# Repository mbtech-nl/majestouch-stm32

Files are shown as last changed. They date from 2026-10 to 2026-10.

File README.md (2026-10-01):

# majestouch-stm32

A drop-in replacement controller for the full-size Filco Majestouch, built
around an STM32F072. It replaces the stock daughterboard, plugs into the same
36-pin header on the main PCB and runs [QMK](https://qmk.fm); the QMK keyboard
definition is included.

> [!WARNING]
> **Untested.** The first boards are on order and have not been built or
> verified on a keyboard yet. Order and build at your own risk until this
> notice is gone.

<p align="center">
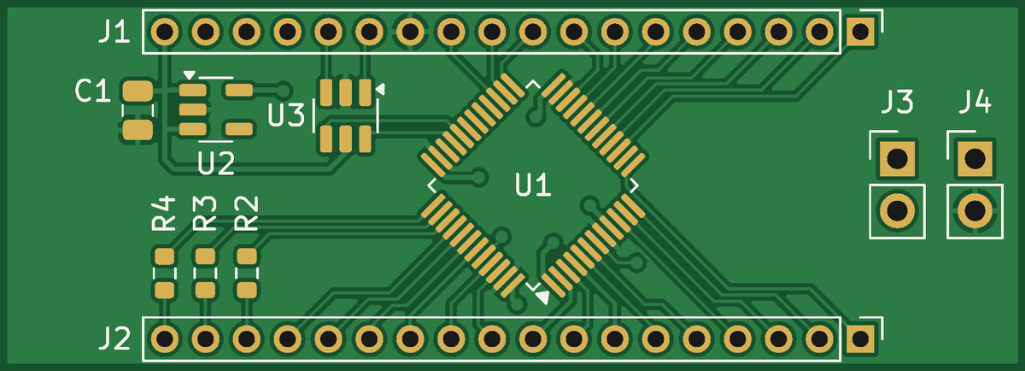
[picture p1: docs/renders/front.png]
Component side: STM32F072 at 45 degrees between the two header rows, USB ESD chip, LDO and LED resistors
  
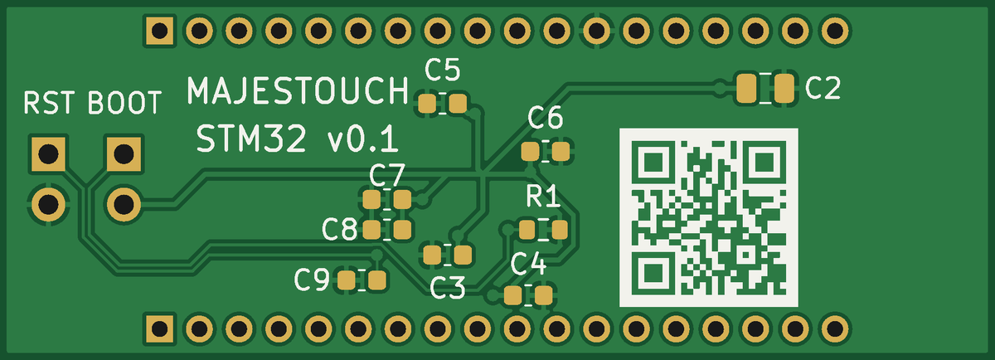
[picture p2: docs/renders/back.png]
Outward side: decoupling capacitors, BOOT and RST jumper holes, name, version and a QR code to this repository
  
</p>
<p align="center"><sub>Component side (faces the main PCB) and outward side, rendered from the KiCad board.</sub></p>

## Background

I was looking for a replacement for my 2010 Majestouch, but gave it a full
service and fresh keycaps instead. Reading up on it, I came across the
[Kitten Paw](https://deskthority.net/wiki/Costar_replacement_controllers)
(ATmega32U2 + 74HC154), the replacement controller for Costar boards such as
the Filco, about a decade after everyone else did, and
[Majestouch-2-TKL-Replacement-Controller](https://github.com/calliah333/Majestouch-2-TKL-Replacement-Controller),
which does the same for the Majestouch 2 TKL with an STM32.

PS/2 left my desk a long time ago, and over USB the stock controller only does
6KRO. I wanted my NKRO back, so I tried making one myself. It's my first open
source hardware project, and the design turned out to be quite
straightforward. It takes the STM32 approach to the full-size board and keeps
it simple:

- **STM32F072CBT6**: crystal-less USB (HSI48 + clock recovery), internal
  flash, ROM bootloader with USB DFU, and 5 V-tolerant pins for the lock LEDs.
  All 26 matrix lines are scanned directly, with no decoder chip.
- **NKRO over USB** (on by default in the QMK definition), where the stock
  controller only did 6KRO over USB.
- **16 components**, LQFP-48 and 0603/0805 passives: hand-solderable.
- USB ESD protection (USBLC6-2SC6) and a 3.3 V LDO (AP2112K-3.3).
- 50 × 18 mm, 2 layers, standard process at any PCB fab.

## Compatibility

Built for and measured on a full-size ANSI Majestouch with main PCB
`CST 104/5/6 Main PCBA Rev 1.2` and stock daughterboard
`CST-DAUGHTER PCBA Rev 3.1 ESD`.

The full-size Filcos below share the same 36-pin header and matrix according
to deskthority, and the Kitten Paw is listed for the same main PCBs, so they
are expected to work, but are untested with this board:

| Keyboard | Main PCB |
|---|---|
| Majestouch (FKBN104/105) | CST-FKB/N-104/5/6 Main PCBA Rev 1.0 / 1.2 (2010) |
| Majestouch Linear R | CST-F104/5/6/8 Main PCB Rev 2.1 (2010) |
| Majestouch 2 | CST-F104/5/6/8 Main PCB Rev 3.0 (2012) |

Full NKRO needs a diode per key. Filco marks those boards with an N in the
model code (FKB**N**…, "N-key rollover using separate diodes"); the cheaper
2KRO models without it work too, but ghost on some key combinations.

Compare your stock controller with the pinout below before fitting. The QMK
definition currently has the ANSI layout only; ISO boards work electrically
but need an ISO layout for the two extra keys. The Majestouch TKL uses a
different header and does not fit.

## Repository

```
kicad/                       KiCad 7 project (schematic, board, design rules)
firmware/majestouch_stm32/   QMK keyboard definition
tools/check.py               validation: schematic, firmware pins and board
tools/fab.py                 fabrication package (Gerbers, drill, BOM)
docs/                        board renders, photos of the stock controller
```

`tools/check.py` checks the schematic against the STM32 datasheet pinout and
the Filco header map, checks that every pin in the QMK definition lands on the
right net, and runs KiCad's design rule check on the board. It needs KiCad 7
(`kicad-cli` and the `pcbnew` Python module).

## Header pinout

From the Filco Majestouch table on deskthority's
[controller matrix traces](https://deskthority.net/wiki/Controller_matrix_traces)
page, cross-checked pin for pin against the
[Kitten Paw schematic](https://deskthority.net/wiki/File:Kitten_Paw_20160418_Schematic.svg).
The component side
faces the main PCB; seen from that side, pin 1 is top-right, pins 1–18 run
right to left, and pin 19 sits directly below pin 1.

| Pin | Signal | STM32 | | Pin | Signal | STM32 |
|---|---|---|---|---|---|---|
| 1 | COL0 | PA5 | | 19 | ROW_K | PA3 |
| 2 | ROW_A | PA6 | | 20 | COL1 | PA2 |
| 3 | ROW_B | PA7 | | 21 | ROW_L | PA1 |
| 4 | ROW_C | PB0 | | 22 | COL2 | PA0 |
| 5 | ROW_D | PB1 | | 23 | COL3 | PF1 |
| 6 | ROW_E | PB2 | | 24 | ROW_M | PF0 |
| 7 | ROW_F | PB10 | | 25 | ROW_N | PC15 |
| 8 | ROW_G | PB11 | | 26 | ROW_O | PC14 |
| 9 | ROW_H | PB12 | | 27 | ROW_P | PC13 |
| 10 | ROW_I | PB13 | | 28 | ROW_Q | PB9 |
| 11 | ROW_J | PB14 | | 29 | COL4 | PB8 |
| 12 | GND | | | 30 | ROW_R | PB7 |
| 13 | USB D+ | ESD → PA12 | | 31 | COL5 | PB6 |
| 14 | USB D− | ESD → PA11 | | 32 | COL6 | PB5 |
| 15 | n/c | | | 33 | COL7 | PB4 |
| 16 | n/c | | | 34 | LED Num Lock | PB3 |
| 17 | n/c | | | 35 | LED Caps Lock | PA15 |
| 18 | VBUS | LDO in | | 36 | LED Scroll Lock | PA14 |

Pins 15 and 16 are tied to GND on the main PCB; this board leaves 15–17
unconnected.

<p align="center">
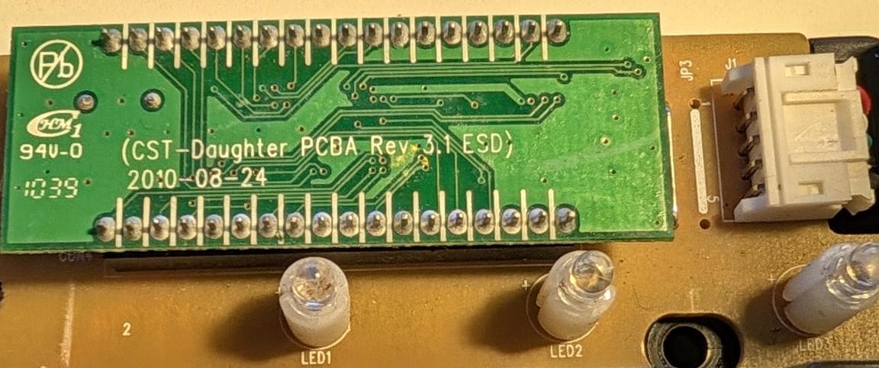
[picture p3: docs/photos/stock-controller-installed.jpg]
Stock Filco controller installed in the keyboard, solder side up, next to the lock LEDs and the USB cable connector
  
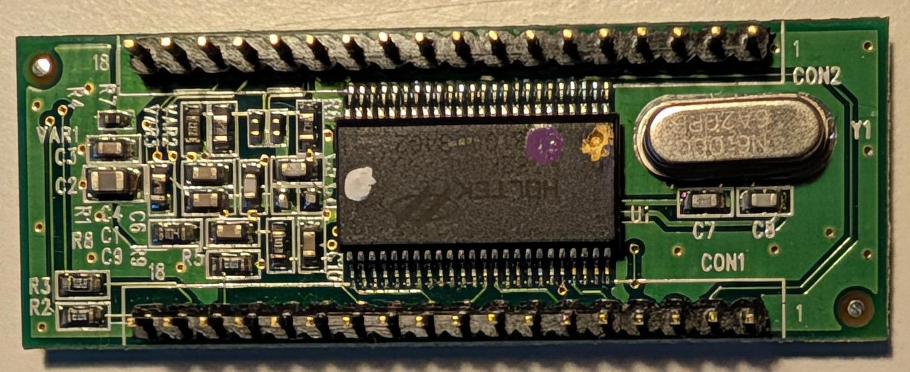
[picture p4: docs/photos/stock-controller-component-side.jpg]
Stock Filco controller removed, component side: Holtek MCU, crystal and the two header rows CON2 (pins 1-18) and CON1 (pins 19-36)
  
</p>
<p align="center"><sub>The stock controller this board replaces: installed, solder side up, next to the lock LEDs and the USB cable connector; and removed, component side, oriented like the render above (CON2 = pins 1–18 on top, pin 1 at the right).</sub></p>

## Circuit

- **USB**: D+/D− pass through the USBLC6-2SC6 flow-through (in on pins 1/3,
  out on 6/4), so no route bypasses the clamp. The STM32's internal pull-up
  handles D+.
- **Power**: VBUS → AP2112K-3.3. Each MCU supply pin has its own decoupling
  cap: 1 µF + 10 nF on VDDA, 100 nF on VDD, VDDIO2 and VBAT.
- **Matrix**: 18 rows driven, 8 columns read (QMK `COL2ROW`). The main PCB
  has no pull-ups to 5 V on the matrix lines, so the 3.6 V-only pins
  (PA0–PA7, PB0/PB1) are safe.
- **Lock LEDs**: the LED anodes sit on +5 V on the main PCB. The MCU sinks
  each LED through a 10 k resistor from a 5 V-tolerant pin in open-drain mode,
  like the stock controller (~0.3 mA).
- **BOOT / RESET**: 2.54 mm jumper holes. BOOT0 has a 10 k pull-down, NRST
  100 nF to GND.

**Board:** 50 × 18 mm, 2 layers, 1.2 mm FR-4. 0.15 mm tracks and clearance
(0.25 mm for power), 0.3 mm vias, GND pour on both sides. The MCU sits at 45°
so each side fans out to one header row. ICs, C1 and the LED resistors are on
the component side (facing the main PCB), the other passives on the outward
side. The outward side carries the reference designators, BOOT/RST labels and
a QR code linking to this repository.

## Making one

> [!CAUTION]
> Seriously: don't build one yet. Wait until the first boards have been
> assembled and tested, and this banner is gone.

### Board

```sh
cd tools
python3 check.py   # validate first
python3 fab.py
```

This builds `kicad/fab/majestouch_stm32-gerbers-<rev>.zip` (Gerbers and drill
files, accepted by any PCB fab) plus `bom.csv` with the parts used and what an
equivalent needs. Tagged releases have both attached, built and validated by GitHub
Actions (`.github/workflows/release.yml`).

Order settings: 2 layers, FR-4, 1.2 mm (the stock board's thickness; 1.6 mm
fits too), HASL lead-free or ENIG. The design stays within standard rules
(0.15 mm track/space, 0.3 mm drills). If your fab prints an order number on
the board (JLCPCB does by default), choose the option without it, so it
doesn't land on the QR code. `cpl.csv` (pick-and-place) is only needed if the
fab assembles the board.

### Parts

| Ref | Part | Package |
|---|---|---|
| U1 | STM32F072CBT6 | LQFP-48 |
| U2 | AP2112K-3.3 | SOT-23-5 |
| U3 | USBLC6-2SC6 | SOT-23-6 |
| C1 | 4.7 µF | 0805 |
| C2 | 10 µF | 0805 |
| C3–C6, C9 | 100 nF | 0603 |
| C7 | 1 µF | 0603 |
| C8 | 10 nF | 0603 |
| R1–R4 | 10 k | 0603 |
| J1, J2 | 2.0 mm pin header, 1 × 40 strip snapped to 2 × 18 | |
| J3, J4 | 2.54 mm 1 × 2 header (optional) | |

Any equivalent part works: X5R/X7R capacitors at 10 V or more, 1 % or 5 %
resistors.

### Assembly

U1, U2, U3, C1 and R2–R4 go on the component side, the other passives on the
back; every part is labelled on the silkscreen. Mind the pin-1 triangles on
U1, U2 and U3: U2 and U3 short VBUS to GND when rotated. Solder the pin
headers last, with the plastic on the component side, then fit the board in
place of the stock controller.

### Firmware

Copy `firmware/majestouch_stm32` into `qmk_firmware/keyboards/`, then:

```sh
qmk compile -kb majestouch_stm32 -km default
```

First flash: bridge the BOOT jumper while plugging in USB (or bridge BOOT and
tap RESET) to start the STM32's DFU bootloader, then
`qmk flash -kb majestouch_stm32 -km default`. After that, hold Esc while
plugging in to get back to the bootloader.

The default keymap is a standard full-size ANSI layout. The Caps/Num/Scroll
LEDs follow the host's lock state.

## Verified on the keyboard

Measured on the target keyboard before ordering:

- outline and header position match the stock board (1:1 print);
- no connection from VBUS to any matrix pin on the main PCB;
- lock LED anodes on +5 V, active low;
- enough height between the boards; stock board 1.2 mm thick.

## References

- [Controller matrix traces](https://deskthority.net/wiki/Controller_matrix_traces)
  (deskthority wiki): the Filco Majestouch header pinout and matrix.
- [Kitten Paw schematic](https://deskthority.net/wiki/File:Kitten_Paw_20160418_Schematic.svg)
  by Bpiphany (public domain): the reference replacement controller for the
  full-size Filco, used to cross-check the header.
- [Costar replacement controllers](https://deskthority.net/wiki/Costar_replacement_controllers)
  (deskthority wiki): the Kitten Paw and its relatives.
- [Majestouch-2-TKL-Replacement-Controller](https://github.com/calliah333/Majestouch-2-TKL-Replacement-Controller):
  an STM32 replacement controller for the Majestouch 2 TKL.
- [STM32F072CB datasheet](https://www.st.com/resource/en/datasheet/stm32f072cb.pdf) (DS9826),
  [USBLC6-2 datasheet](https://www.st.com/resource/en/datasheet/usblc6-2.pdf),
  [AP2112 datasheet](https://www.diodes.com/assets/Datasheets/AP2112.pdf).

## License

MIT, see [LICENSE](LICENSE). This covers the hardware, the tools and the QMK
keyboard definition. Firmware built with QMK includes QMK itself, which is
GPL-2.0-or-later, so compiled binaries fall under the GPL.

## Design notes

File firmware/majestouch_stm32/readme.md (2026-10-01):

# majestouch_stm32

QMK keyboard definition for the [majestouch-stm32](https://github.com/mbtech-nl/majestouch-stm32)
replacement controller (STM32F072) for the full-size Filco Majestouch.

* Keyboard maintainer: [mbtech-nl](https://github.com/mbtech-nl)
* Hardware supported: majestouch-stm32 controller board in a full-size Filco Majestouch
* Hardware availability: https://github.com/mbtech-nl/majestouch-stm32

Copy this folder into `qmk_firmware/keyboards/`, then:

    qmk compile -kb majestouch_stm32 -km default
    qmk flash -kb majestouch_stm32 -km default

## Bootloader

* **First flash**: bridge the BOOT jumper while plugging in USB (or bridge BOOT and tap RESET).
* **Bootmagic reset**: hold Esc while plugging in.

## License

The files in this folder are MIT licensed, like the rest of the project.
Firmware built from them includes QMK, which is GPL-2.0-or-later, so compiled
binaries are covered by the GPL.

`tools/check.py` verifies the matrix and LED pins in these files against the
schematic.

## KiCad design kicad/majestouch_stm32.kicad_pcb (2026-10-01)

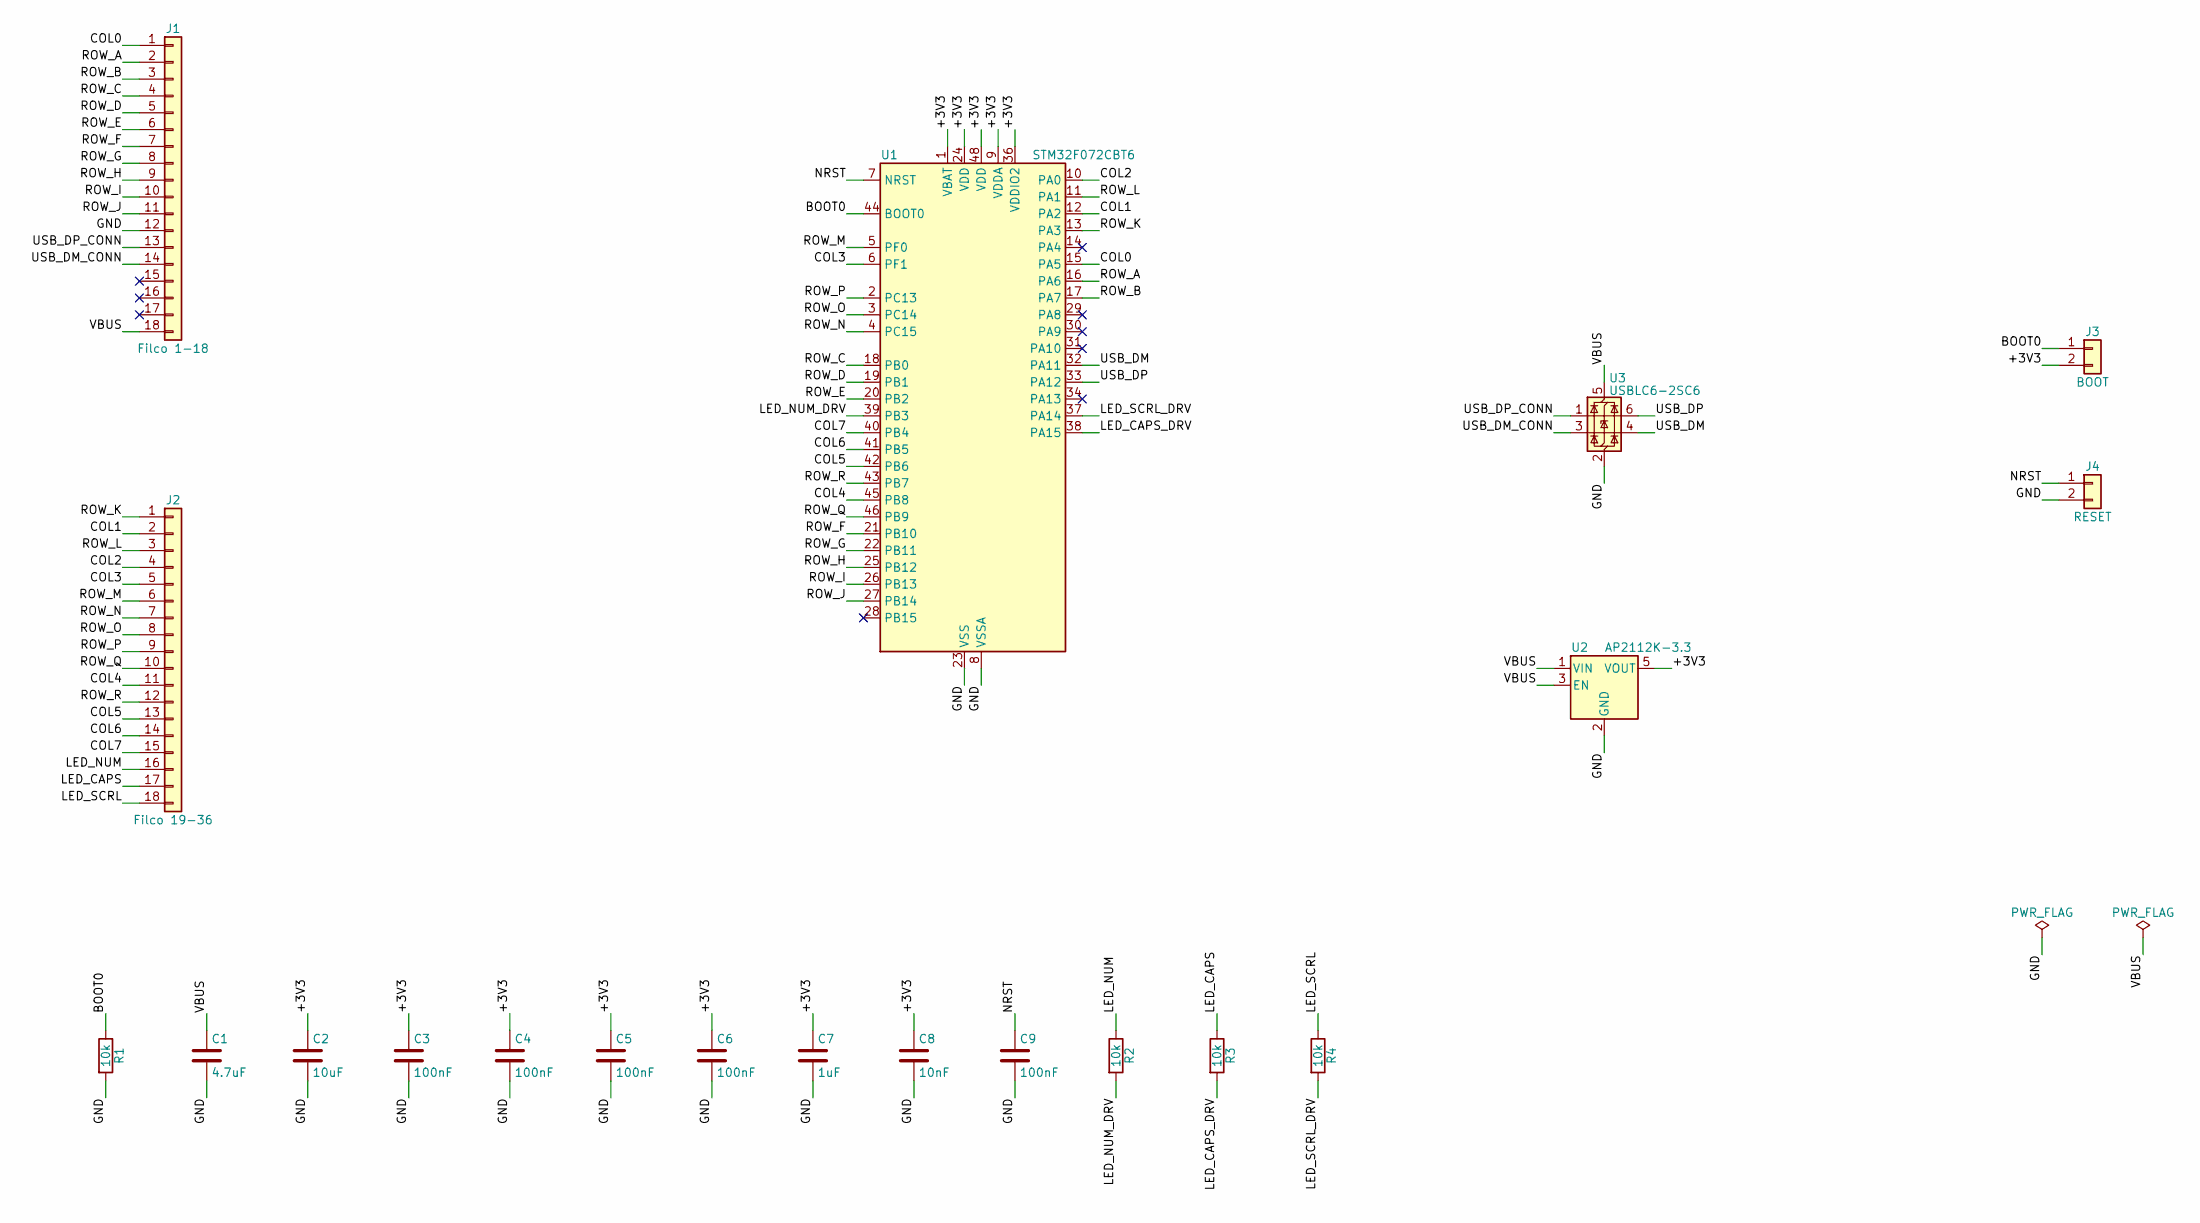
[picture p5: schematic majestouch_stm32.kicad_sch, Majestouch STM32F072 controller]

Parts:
C1: 4.7uF; C_0805_2012Metric
C2: 10uF; C_0805_2012Metric
C3, C4, C5, C6, C9: 100nF; C_0603_1608Metric
C7: 1uF; C_0603_1608Metric
C8: 10nF; C_0603_1608Metric
J1: Filco 1-18; PinHeader_1x18_P2.00mm_Vertical
J2: Filco 19-36; PinHeader_1x18_P2.00mm_Vertical
J3: BOOT; PinHeader_1x02_P2.54mm_Vertical
J4: RESET; PinHeader_1x02_P2.54mm_Vertical
R1, R2, R3, R4: 10k; R_0603_1608Metric
U1: STM32F072CBT6; LQFP-48_7x7mm_P0.5mm
U2: AP2112K-3.3; SOT-23-5
U3: USBLC6-2SC6; SOT-23-6

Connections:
/+3V3: C2.1, C3.1, C4.1, C5.1, C6.1, C7.1, C8.1, J3.2, U1.1 (VBAT), U1.9 (VDDA), U1.24 (VDD), U1.36 (VDDIO2), U1.48 (VDD), U2.5 (VOUT)
/BOOT0: J3.1, R1.1, U1.44 (BOOT0)
/COL0: J1.1, U1.15 (PA5)
/COL1: J2.2, U1.12 (PA2)
/COL2: J2.4, U1.10 (PA0)
/COL3: J2.5, U1.6 (PF1)
/COL4: J2.11, U1.45 (PB8)
/COL5: J2.13, U1.42 (PB6)
/COL6: J2.14, U1.41 (PB5)
/COL7: J2.15, U1.40 (PB4)
/GND: C1.2, C2.2, C3.2, C4.2, C5.2, C6.2, C7.2, C8.2, C9.2, J1.12, J4.2, R1.2, U1.8 (VSSA), U1.23 (VSS), U1.35 (VSS), U1.47 (VSS), U2.2 (GND), U3.2 (GND)
/LED_CAPS: J2.17, R3.1
/LED_CAPS_DRV: R3.2, U1.38 (PA15)
/LED_NUM: J2.16, R2.1
/LED_NUM_DRV: R2.2, U1.39 (PB3)
/LED_SCRL: J2.18, R4.1
/LED_SCRL_DRV: R4.2, U1.37 (PA14)
/NRST: C9.1, J4.1, U1.7 (NRST)
/ROW_A: J1.2, U1.16 (PA6)
/ROW_B: J1.3, U1.17 (PA7)
/ROW_C: J1.4, U1.18 (PB0)
/ROW_D: J1.5, U1.19 (PB1)
/ROW_E: J1.6, U1.20 (PB2)
/ROW_F: J1.7, U1.21 (PB10)
/ROW_G: J1.8, U1.22 (PB11)
/ROW_H: J1.9, U1.25 (PB12)
/ROW_I: J1.10, U1.26 (PB13)
/ROW_J: J1.11, U1.27 (PB14)
/ROW_K: J2.1, U1.13 (PA3)
/ROW_L: J2.3, U1.11 (PA1)
/ROW_M: J2.6, U1.5 (PF0)
/ROW_N: J2.7, U1.4 (PC15)
/ROW_O: J2.8, U1.3 (PC14)
/ROW_P: J2.9, U1.2 (PC13)
/ROW_Q: J2.10, U1.46 (PB9)
/ROW_R: J2.12, U1.43 (PB7)
/USB_DM: U1.32 (PA11), U3.4 (I/O2)
/USB_DM_CONN: J1.14, U3.3 (I/O2)
/USB_DP: U1.33 (PA12), U3.6 (I/O1)
/USB_DP_CONN: J1.13, U3.1 (I/O1)
/VBUS: C1.1, J1.18, U2.1 (VIN), U2.3 (EN), U3.5 (VBUS)

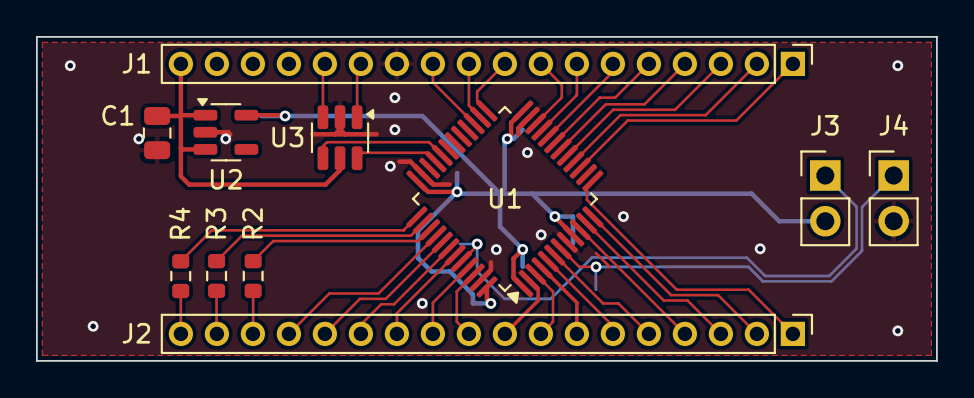
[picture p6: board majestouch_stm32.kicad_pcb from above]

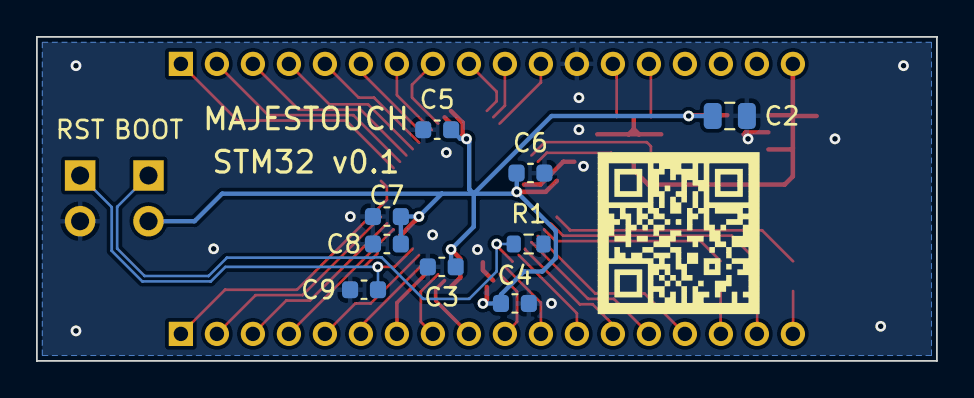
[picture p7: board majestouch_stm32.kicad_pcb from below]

Board: 2 copper layers, 50.0 x 18.0 mm, 20 parts (9 on the bottom side), 41 nets.

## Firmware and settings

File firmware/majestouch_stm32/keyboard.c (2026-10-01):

// Copyright 2026 MB Tech
// SPDX-License-Identifier: MIT

#include "quantum.h"

// The Filco lock LED anodes are tied to +5 V on the main PCB. These pins are
// 5 V tolerant only as inputs/open-drain, so never drive them push-pull high.
static const pin_t lock_leds[] = {B3, A15, A14}; // num, caps, scroll

void keyboard_pre_init_kb(void) {
    for (uint8_t i = 0; i < ARRAY_SIZE(lock_leds); i++) {
        gpio_write_pin_high(lock_leds[i]);
        gpio_set_pin_output_open_drain(lock_leds[i]);
    }
    keyboard_pre_init_user();
}

bool led_update_kb(led_t state) {
    bool res = led_update_user(state);
    if (res) {
        gpio_write_pin(lock_leds[0], !state.num_lock);
        gpio_write_pin(lock_leds[1], !state.caps_lock);
        gpio_write_pin(lock_leds[2], !state.scroll_lock);
    }
    return res;
}

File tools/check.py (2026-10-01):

#!/usr/bin/env python3
"""Validate the design.

  python3 check.py            schematic, firmware and board checks
  python3 check.py --no-board skip the board checks (no pcbnew module needed)

1. Schematic: exports the netlist with kicad-cli and checks it against the
   Filco header map and STM32F072 pin tables written out here from the
   datasheet (DS9826), independently of the KiCad symbols.
2. Firmware: every pin in firmware/majestouch_stm32 (keyboard.json matrix,
   keyboard.c lock LEDs) must land on the right net in the schematic.
3. Board: footprints and pad nets match the schematic, and KiCad's DRC is
   clean (as saved). Headless pcbnew can't see the footprint libraries, so
   "lib_footprint_issues" is ignored.

Exits non-zero on any error. Needs KiCad 7 (kicad-cli, and the pcbnew Python
module for the board checks).
"""
import argparse
import json
import os
import re
import subprocess
import sys
import tempfile

ROOT = os.path.normpath(os.path.join(os.path.dirname(os.path.abspath(__file__)), '..'))
PROJECT = 'majestouch_stm32'
SCH = os.path.join(ROOT, 'kicad', PROJECT + '.kicad_sch')
PCB = os.path.join(ROOT, 'kicad', PROJECT + '.kicad_pcb')
FW = os.path.join(ROOT, 'firmware', PROJECT)

# Full-size Filco header (deskthority "Controller matrix traces", Kitten Paw).
# J1 = header pins 1-18, J2 = 19-36 (J2 pin n is header pin n + 18).
HEADER = {
    1: 'COL0', 2: 'ROW_A', 3: 'ROW_B', 4: 'ROW_C', 5: 'ROW_D', 6: 'ROW_E',
    7: 'ROW_F', 8: 'ROW_G', 9: 'ROW_H', 10: 'ROW_I', 11: 'ROW_J',
    12: 'GND', 13: 'USB_DP_CONN', 14: 'USB_DM_CONN', 15: None, 16: None,
    17: None, 18: 'VBUS',
    19: 'ROW_K', 20: 'COL1', 21: 'ROW_L', 22: 'COL2', 23: 'COL3', 24: 'ROW_M',
    25: 'ROW_N', 26: 'ROW_O', 27: 'ROW_P', 28: 'ROW_Q', 29: 'COL4',
    30: 'ROW_R', 31: 'COL5', 32: 'COL6', 33: 'COL7',
    34: 'LED_NUM', 35: 'LED_CAPS', 36: 'LED_SCRL',
}
ROWS = [f'ROW_{c}' for c in 'ABCDEFGHIJKLMNOPQR']
COLS = [f'COL{i}' for i in range(8)]
LEDS = ['LED_NUM', 'LED_CAPS', 'LED_SCRL']   # keyboard.c order: num, caps, scroll

# STM32F072 LQFP-48 pinout (DS9826) and its 5 V-tolerant (FT) pins in use here
STM32_PIN = {name: i + 1 for i, name in enumerate(
    'VBAT PC13 PC14 PC15 PF0 PF1 NRST VSSA VDDA PA0 PA1 PA2 PA3 PA4 PA5 PA6 PA7 PB0 PB1 '
    'PB2 PB10 PB11 VSS VDD PB12 PB13 PB14 PB15 PA8 PA9 PA10 PA11 PA12 PA13 VSS VDDIO2 '
    'PA14 PA15 PB3 PB4 PB5 PB6 PB7 BOOT0 PB8 PB9 VSS VDD'.split())}
STM32_NAME = {str(n): name for name, n in STM32_PIN.items()}   # VSS/VDD repeat: checked by number
STM32_FT = {'PA8', 'PA9', 'PA10', 'PA13', 'PA14', 'PA15', 'PB3', 'PB4', 'PB5', 'PB6', 'PB7',
            'PB8', 'PB9'}

errors = []


def error(msg):
    errors.append(msg)
    print('ERROR', msg)


# --- minimal s-expression reader for KiCad's netlist ---------------------------
_TOKEN = re.compile(r'\s*(\(|\)|"(?:\\.|[^"\\])*"|[^\s()"]+)')


def parse(text):
    pos, stack, cur = 0, [], []
    while (m := _TOKEN.match(text, pos)):
        tok, pos = m.group(1), m.end()
        if tok == '(':
            stack.append(cur)
            cur = []
        elif tok == ')':
            done, cur = cur, stack.pop()
            cur.append(done)
        else:
            cur.append(tok[1:-1].replace('\\"', '"') if tok.startswith('"') else tok)
    return cur[0]


def find(node, key):
    return [x for x in node if isinstance(x, list) and x and x[0] == key]


def first(node, key):
    r = find(node, key)
    return r[0] if r else None


def netlist():
    """{net: {(ref, pin)}} and {(ref, pin): net}, names without the '/' prefix."""
    with tempfile.TemporaryDirectory() as tmp:
        out = os.path.join(tmp, 'netlist.net')
        r = subprocess.run(['kicad-cli', 'sch', 'export', 'netlist', '-o', out, SCH],
                           capture_output=True, text=True)
        if r.returncode:
            sys.exit(f'kicad-cli netlist export failed:\n{r.stdout}{r.stderr}')
        tree = parse(open(out).read())
    nets, pin_net = {}, {}
    for n in find(first(tree, 'nets'), 'net'):
        name = first(n, 'name')[1].lstrip('/')
        nodes = {(first(x, 'ref')[1], first(x, 'pin')[1]) for x in find(n, 'node')}
        nets[name] = nodes
        for node in nodes:
            pin_net[node] = name
    return nets, pin_net


# --- 1. schematic -----------------------------------------------------------------
def check_schematic(nets, pin_net):
    def expect(ref, pin, net):
        got = pin_net.get((ref, str(pin)))
        if got != net:
            error(f'{ref}.{pin}: expected {net}, got {got}')

    def refs(net):
        return sorted(r for r, _ in nets.get(net, ()))

    for hp, net in HEADER.items():
        ref, pin = ('J1', hp) if hp <= 18 else ('J2', hp - 18)
        if net:
            expect(ref, pin, net)
        elif not pin_net.get((ref, str(pin)), '').startswith('unconnected'):
            error(f'{ref}.{pin} (header {hp}) should be unconnected')

    # matrix: header straight to a GPIO, nothing else on the line
    for net in ROWS + COLS:
        if refs(net) not in (['J1', 'U1'], ['J2', 'U1']):
            error(f'{net}: expected header + U1 only, got {sorted(nets.get(net, ()))}')
            continue
        pin = next(p for r, p in nets[net] if r == 'U1')
        if not STM32_NAME.get(pin, '').startswith('P') or STM32_NAME[pin] in ('PA11', 'PA12'):
            error(f'{net}: on U1 pin {pin} ({STM32_NAME.get(pin)}), not a free GPIO')

    # lock LEDs: header pin -> series resistor -> 5 V-tolerant MCU pin
    for led in LEDS:
        hdr, drv = refs(led), refs(led + '_DRV')
        res = (set(hdr) & set(drv)) - {'J2', 'U1'}
        if len(hdr) != 2 or 'J2' not in hdr or len(drv) != 2 or 'U1' not in drv or len(res) != 1:
            error(f'{led}: expected header -> resistor -> U1, got {hdr} / {drv}')
            continue
        pin = next(p for r, p in nets[led + '_DRV'] if r == 'U1')
        if STM32_NAME.get(pin) not in STM32_FT:
            error(f'{led}_DRV on U1 pin {pin} ({STM32_NAME.get(pin)}), which is not 5 V tolerant')

    # USB: flow-through ESD, header side in on 1/3, MCU side out on 6/4
    expect('U3', 1, 'USB_DP_CONN'); expect('U3', 6, 'USB_DP')
    expect('U3', 3, 'USB_DM_CONN'); expect('U3', 4, 'USB_DM')
    expect('U3', 2, 'GND'); expect('U3', 5, 'VBUS')
    expect('U1', STM32_PIN['PA12'], 'USB_DP'); expect('U1', STM32_PIN['PA11'], 'USB_DM')
    for net, want in (('USB_DP_CONN', ['J1', 'U3']), ('USB_DM_CONN', ['J1', 'U3']),
                      ('USB_DP', ['U1', 'U3']), ('USB_DM', ['U1', 'U3'])):
        if refs(net) != want:
            error(f'{net} must only join {want}, got {sorted(nets.get(net, ()))}')

    # power: LDO, MCU supplies, BOOT0 pull-down, NRST
    expect('U2', 1, 'VBUS'); expect('U2', 3, 'VBUS'); expect('U2', 2, 'GND'); expect('U2', 5, '+3V3')
    for pin in (1, 9, 24, 36, 48):          # VBAT, VDDA, VDD, VDDIO2, VDD
        expect('U1', pin, '+3V3')
    for pin in (8, 23, 35, 47):             # VSSA, VSS
        expect('U1', pin, 'GND')
    expect('U1', STM32_PIN['BOOT0'], 'BOOT0'); expect('R1', 1, 'BOOT0'); expect('R1', 2, 'GND')
    expect('U1', STM32_PIN['NRST'], 'NRST')

    for n, v in nets.items():
        if len(v) < 2 and not n.startswith('unconnected'):
            error(f'net {n} has a single node {v}')
    print(f'schematic: {len(nets)} nets, {len({r for r, _ in pin_net})} parts')


# --- 2. firmware ------------------------------------------------------------------
def check_firmware(pin_net):
    def net_of(qmk_pin):                    # QMK "A6" -> PA6 -> U1 pin -> net
        n = STM32_PIN.get('P' + qmk_pin)
        return pin_net.get(('U1', str(n))) if n else None

    kb = json.load(open(os.path.join(FW, 'keyboard.json')))
    if kb.get('processor') != 'STM32F072':
        error(f"keyboard.json: processor {kb.get('processor')}, expected STM32F072")
    if kb.get('diode_direction') != 'COL2ROW':
        error(f"keyboard.json: diode_direction {kb.get('diode_direction')}, expected COL2ROW")
    for kind, want in (('rows', ROWS), ('cols', COLS)):
        got = kb['matrix_pins'][kind]
        if len(got) != len(want):
            error(f'keyboard.json: {len(got)} {kind}, expected {len(want)}')
        for i, (p, net) in enumerate(zip(got, want)):
            if net_of(p) != net:
                error(f'keyboard.json: {kind}[{i}] = {p} is {net_of(p)} in the schematic, expected {net}')

    src = open(os.path.join(FW, 'keyboard.c')).read()
    m = re.search(r'lock_leds\[\]\s*=\s*\{([^}]*)\}', src)
    leds = [p.strip() for p in m.group(1).split(',')] if m else []
    if len(leds) != len(LEDS):
        error(f'keyboard.c: lock_leds = {leds}, expected {len(LEDS)} pins')
    for p, led in zip(leds, LEDS):
        if net_of(p) != led + '_DRV':
            error(f'keyboard.c: lock LED {p} is {net_of(p)} in the schematic, expected {led}_DRV')
    print(f'firmware: {len(ROWS)} rows, {len(COLS)} cols, {len(leds)} LEDs')


# --- 3. board ---------------------------------------------------------------------
def check_board(pin_net):
    import pcbnew
    board = pcbnew.LoadBoard(PCB)           # never saved
    sch_refs = {r for r, _ in pin_net}
    pcb_refs = {fp.GetReference() for fp in board.GetFootprints()}
    if sch_refs != pcb_refs:
        error(f'board vs schematic parts: only on board {sorted(pcb_refs - sch_refs)}, '
              f'only in schematic {sorted(sch_refs - pcb_refs)}')
    pads = 0
    for fp in board.GetFootprints():
        for pad in fp.Pads():
            pads += 1
            got = pad.GetNetname().lstrip('/')
            want = pin_net.get((fp.GetReference(), pad.GetNumber()))
            if got != want:
                error(f'{fp.GetReference()}.{pad.GetNumber()}: board net {got}, schematic {want}')

    with tempfile.TemporaryDirectory() as tmp:
        rpt = os.path.join(tmp, 'drc.rpt')
        pcbnew.WriteDRCReport(board, rpt, pcbnew.EDA_UNITS_MILLIMETRES, True)
        report = open(rpt).read()
    found = re.findall(r'^\[(\w+)\]: (.*)$', report, re.M)
    issues = [(k, msg) for k, msg in found if k != 'lib_footprint_issues']
    for k, msg in issues:
        error(f'DRC {k}: {msg}')
    unconnected = int(re.search(r'Found (\d+) unconnected', report).group(1))
    if unconnected:
        error(f'DRC: {unconnected} unconnected pad(s)')
    print(f'board: {len(pcb_refs)} parts, {pads} pads, DRC {len(issues)} issue(s), '
          f'{unconnected} unconnected')


def main():
    ap = argparse.ArgumentParser(description=__doc__.split('\n')[0])
    ap.add_argument('--no-board', action='store_true', help='skip the board checks (no pcbnew)')
    args = ap.parse_args()
    nets, pin_net = netlist()
    check_schematic(nets, pin_net)
    check_firmware(pin_net)
    if not args.no_board:
        check_board(pin_net)
    print('OK' if not errors else f'{len(errors)} error(s)')
    return not errors


if __name__ == '__main__':
    sys.exit(0 if main() else 1)

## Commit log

2026-10-01 majestouch-stm32 0.1
    Drop-in replacement controller for the full-size Filco Majestouch, built
    around an STM32F072: KiCad 7 project, QMK keyboard definition, validation
    (tools/check.py), fabrication package (tools/fab.py) and a release workflow
    that builds the Gerbers and BOM on version tags.
    [majestouch_stm32.kicad_pcb, majestouch_stm32.kicad_sch]
2026-10-22 Firmware: rename keyboard.c so QMK builds it
    QMK only compiles the keyboard-level C file named after the keyboard
    folder, so keyboard.c was silently skipped and the lock LED pins were
    never configured. Num and Scroll Lock glowed dimly from their reset
    pull-downs.
2026-10-22 README: first board built and tested, drop the untested warnings
    Every key and NKRO work in the keyboard, the lock LEDs follow the host,
    and flashing works over BOOT + RST and later with Bootmagic (Esc).
2026-10-22 Release workflow: build the QMK firmware and attach the .bin
    Builds firmware/majestouch_stm32 against a pinned QMK release (0.34.6,
    the version the first board was tested with) in the qmk_cli container.
    Release notes name the QMK version and the GPL license of the binary;
    the README points to the release binary and dfu-util.
2026-10-22 KiCad 9: upgrade the project files, silkscreen v1.0
    Schematic and board saved in KiCad 9.0.9. The library-mismatch
    warnings are excluded (1 ERC, 20 DRC): the STM32 symbol was redrawn in
    the KiCad 9 library and the footprints differ only in 3D models and
    graphics, pads are identical. 3D model paths now point to the KiCad 9
    .step models. Gerbers exported from v0.1 and from these files with
    KiCad 9.0.9 have the same tracks, vias, pads and zone outline.
    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
2026-10-22 Firmware: USB device version 1.0.0
2026-10-22 README: photos of the first board
    Assembled, installed in the keyboard and next to the stock controller.
